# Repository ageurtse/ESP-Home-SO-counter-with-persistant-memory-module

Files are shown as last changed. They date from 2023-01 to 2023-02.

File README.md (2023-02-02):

# ESP Home, SO 4 channel counter with P1 interface

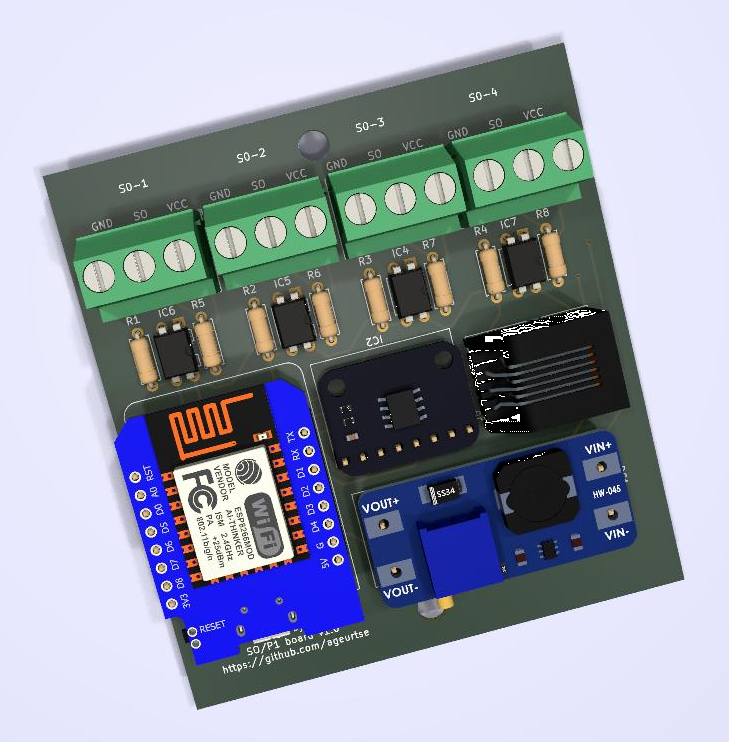
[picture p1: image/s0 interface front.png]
SO/P1 interface board


I wrote this software and developed the hardware because i was in the need of a device which could count my pulses from a water meter and from my solar pannels. 
The default counter from within ESPHome does the thrick, one could also preserve te counted value in the memory off a ESP device. 
But on my electrical meter which counts 2000 pulses per kW it will wearout in a couple of days. 

So i wen't searching and found this beaty which doesn't coast that much at all. 
https://www.adafruit.com/product/1895

After finding the device i need a way to use it in home assistant, that was for me as a hobby programmer the hardes part, first search for a library which could do the trick. 
and second how to interface the library with ESPHome so i could use it. 

For the library a big thanks to @RobTillart for his great library https://github.com/RobTillaart/FRAM_I2C which i'm implementing in it. 

I'm still working on a test setup, next step is to develop a need 4 wat SO circuit and PCB so one could rebuild.

I found a realy big bug in the hardware, the fourth SO input can't be working, becaus off pulling down the TX inpunt on the ESP8266. When pulling this one down at boot, the device won't boot.

## Description about the FRAM module.

FRAM stands for Ferroelectric RAM - https://en.wikipedia.org/wiki/Ferroelectric_RAM

FRAM memory is much faster than EEPROM and almost as fast as (Arduino UNO) RAM. Another important feature FRAM has in common with EEPROM is that FRAM keeps its content after a reboot as it is non-volatile, even for years. That makes it ideal to store configuration or logging data in a project.
## Operational

There are 2 parts that one should keep in mind.

**First:**
One should make use off i2cfram.h this is the interface file between ESPHome and the library from https://github.com/RobTillaart/FRAM_I2C
in this file there is a setup part, where at boot the device is looking for a memory module and initializes it. 
further there are 2 function which could be called from within Lambda

float readfromfram(uint32_t memaddr), which reads from the given adres slot and returns a float value
void writetofram(uint32_t memaddr, float value), writes a float to the given memory slot
because of the use of floats in ESPhome, every memory slot contains 4 bytes. so if one give memaddr 10, it will write or read 4 bytes from addres 40

**Second:**
This is the yaml file.
For every counter i make use of a global variabel, which will be loaded from memory at boot time. 
It is also posible to (re)set te counters from Homeassistant. 

I disabled the timout so one could use the device without home assistant, i did a test run of 2 days without problems. 

There is the need for the custom component to initializes the memory module. 

From within the binary sensor, the global value is added with 1 at a time, on every count the new value is written to the memory module.

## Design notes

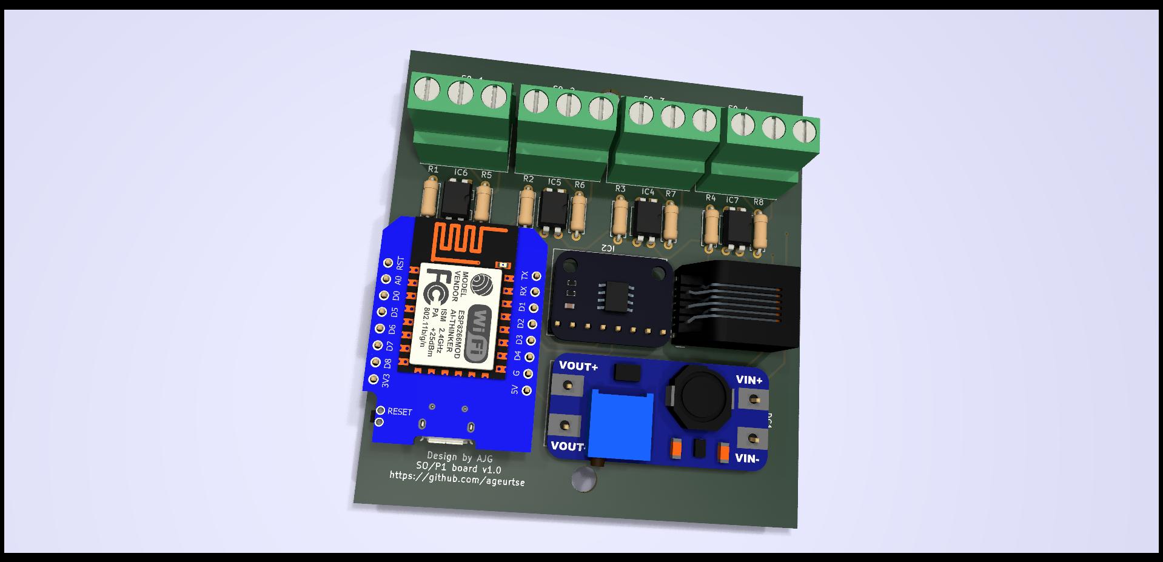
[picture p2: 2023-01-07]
Hardware/s0 interface/s0 interface.jpg

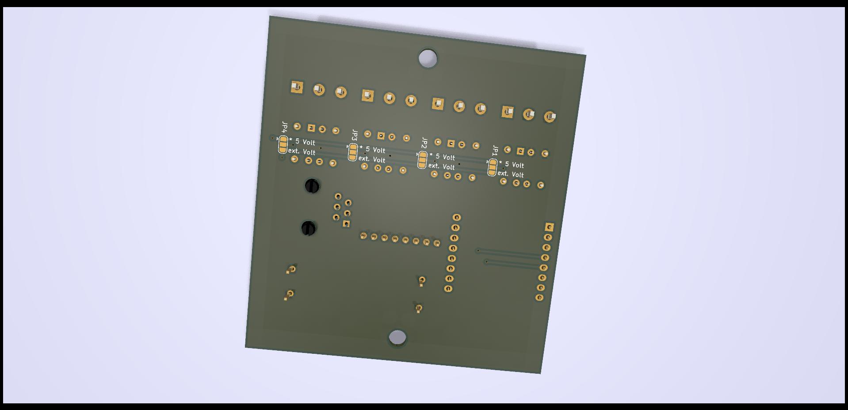
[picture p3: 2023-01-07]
Hardware/s0 interface/s0 interface back .jpg

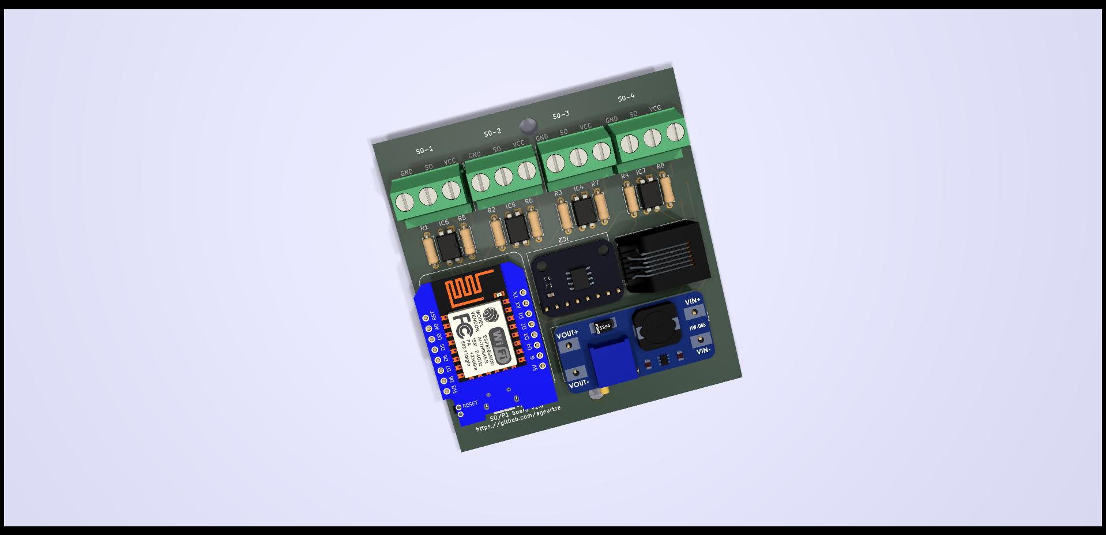
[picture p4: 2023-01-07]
Hardware/s0 interface/s0 interface front.jpg

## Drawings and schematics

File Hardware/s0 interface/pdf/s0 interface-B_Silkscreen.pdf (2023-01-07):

* 5 Volt ext. Volt * 5 Volt ext. Volt * 5 Volt ext. Volt * 5 Volt ext. Volt JP1 JP2 JP3 JP4

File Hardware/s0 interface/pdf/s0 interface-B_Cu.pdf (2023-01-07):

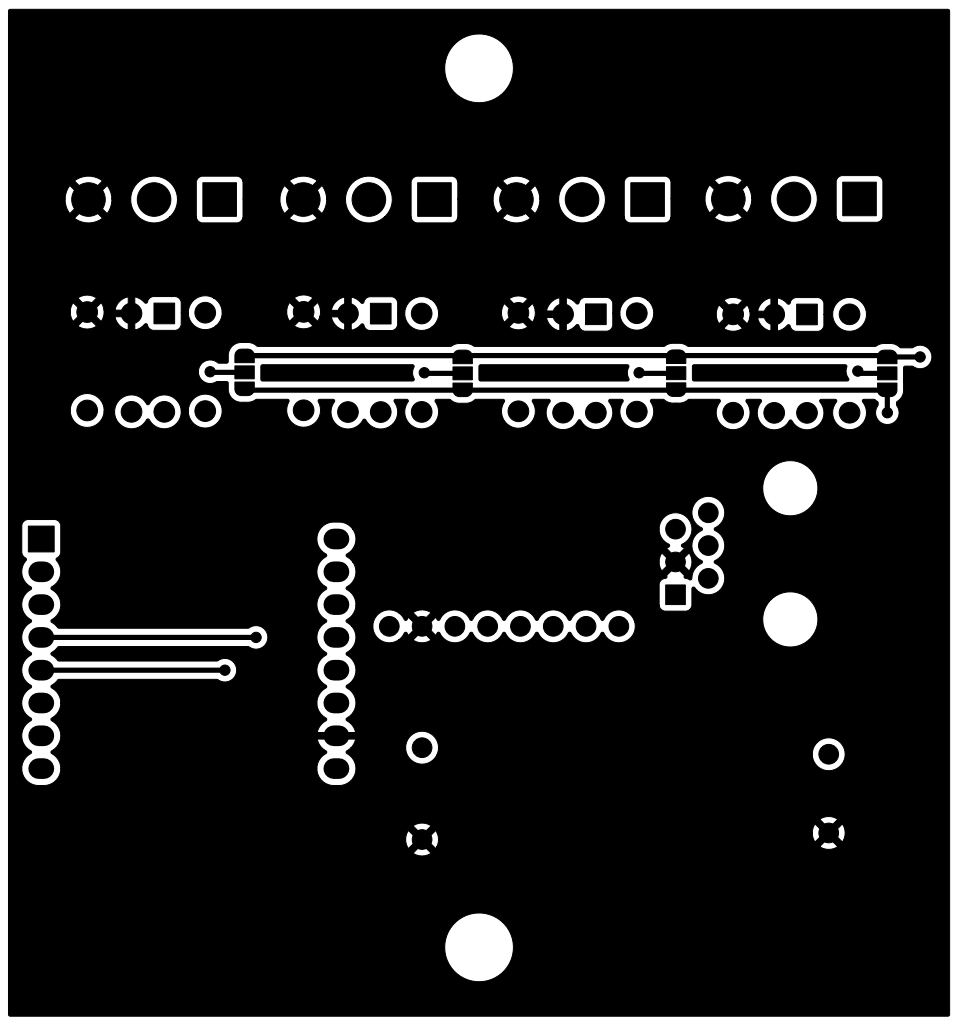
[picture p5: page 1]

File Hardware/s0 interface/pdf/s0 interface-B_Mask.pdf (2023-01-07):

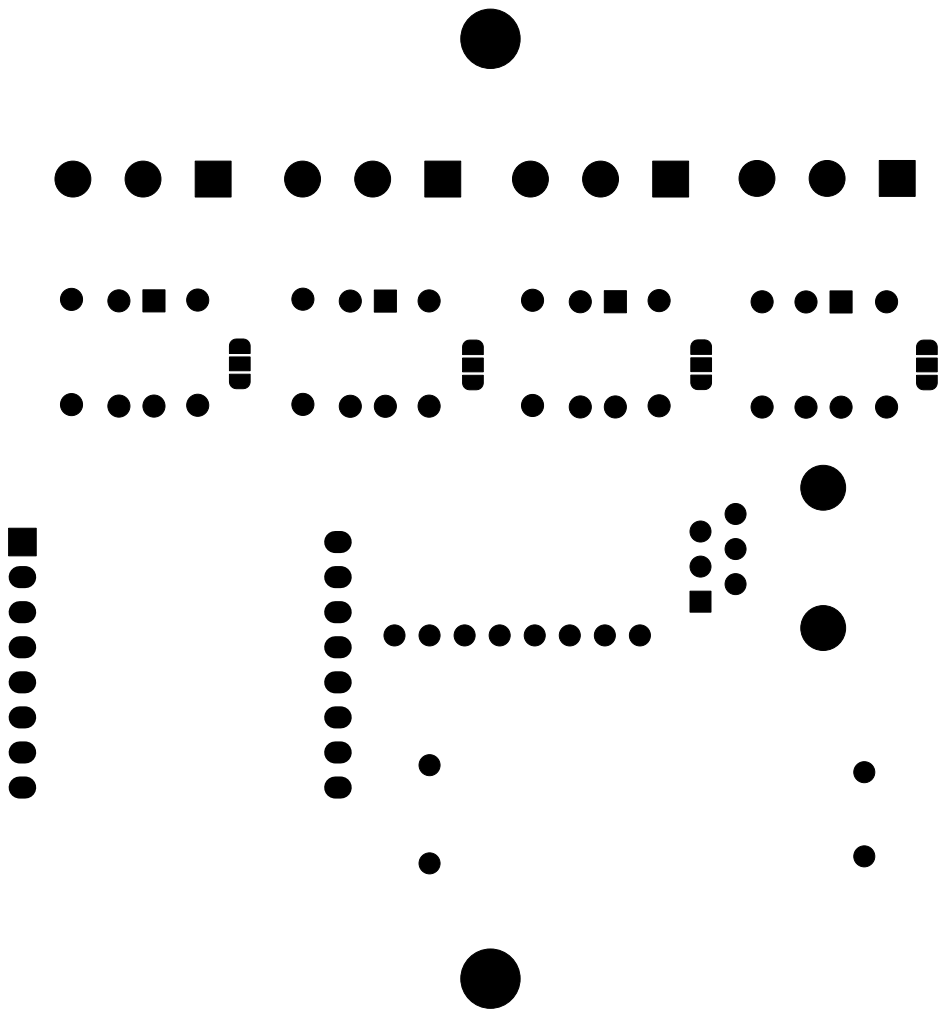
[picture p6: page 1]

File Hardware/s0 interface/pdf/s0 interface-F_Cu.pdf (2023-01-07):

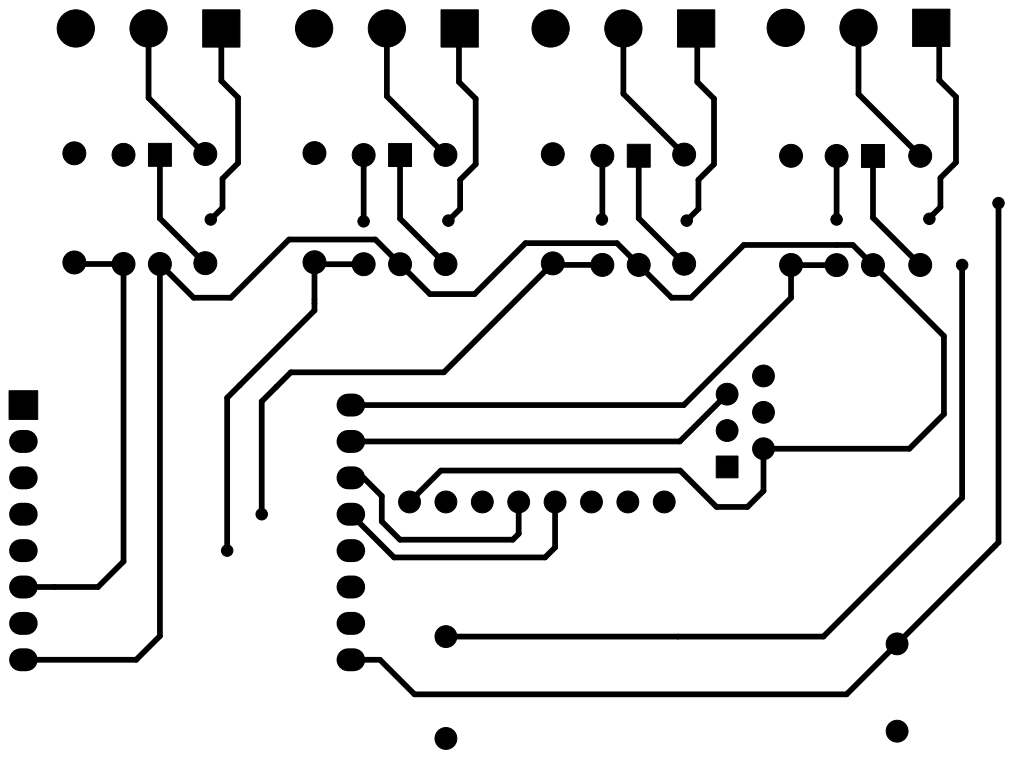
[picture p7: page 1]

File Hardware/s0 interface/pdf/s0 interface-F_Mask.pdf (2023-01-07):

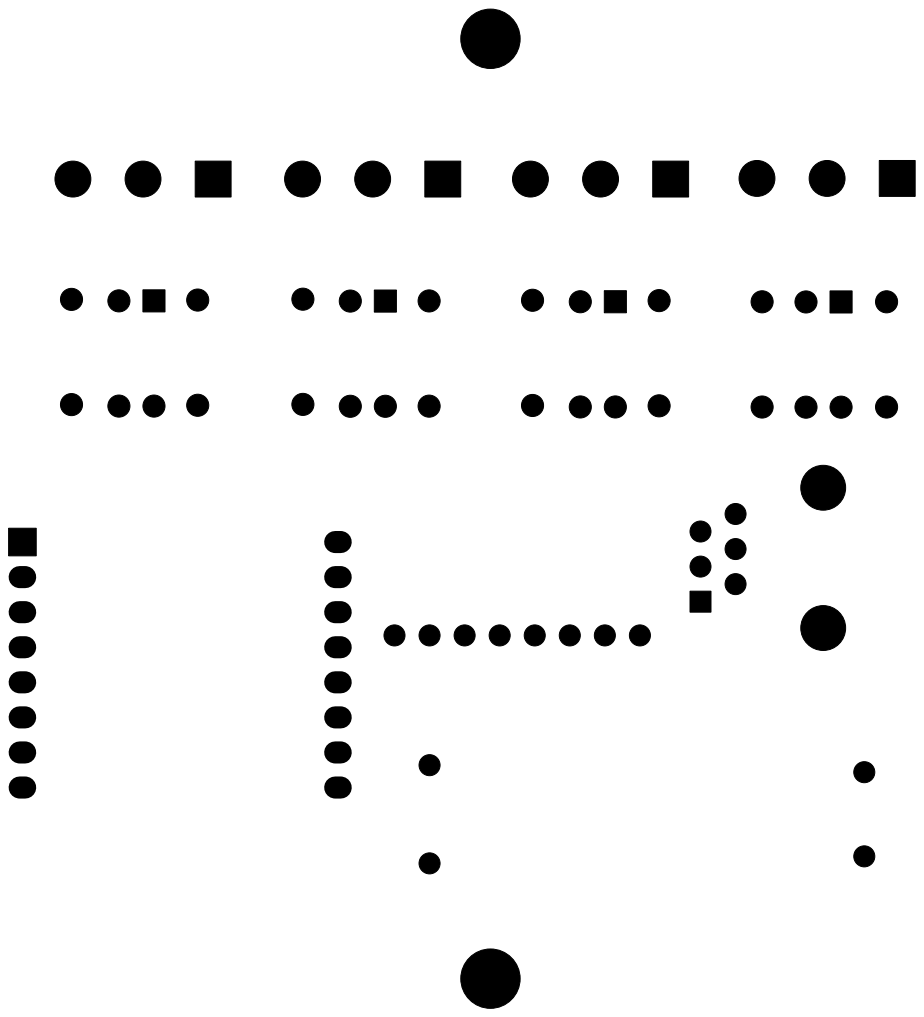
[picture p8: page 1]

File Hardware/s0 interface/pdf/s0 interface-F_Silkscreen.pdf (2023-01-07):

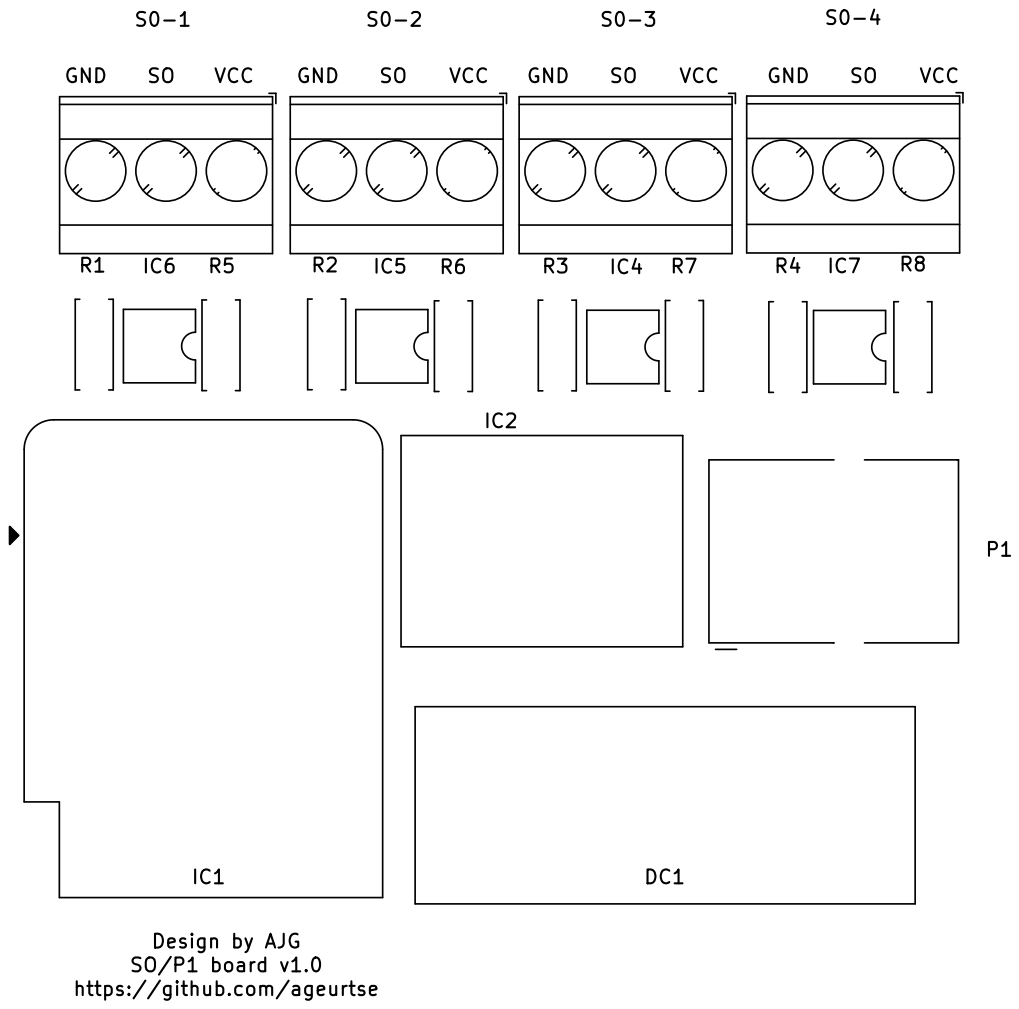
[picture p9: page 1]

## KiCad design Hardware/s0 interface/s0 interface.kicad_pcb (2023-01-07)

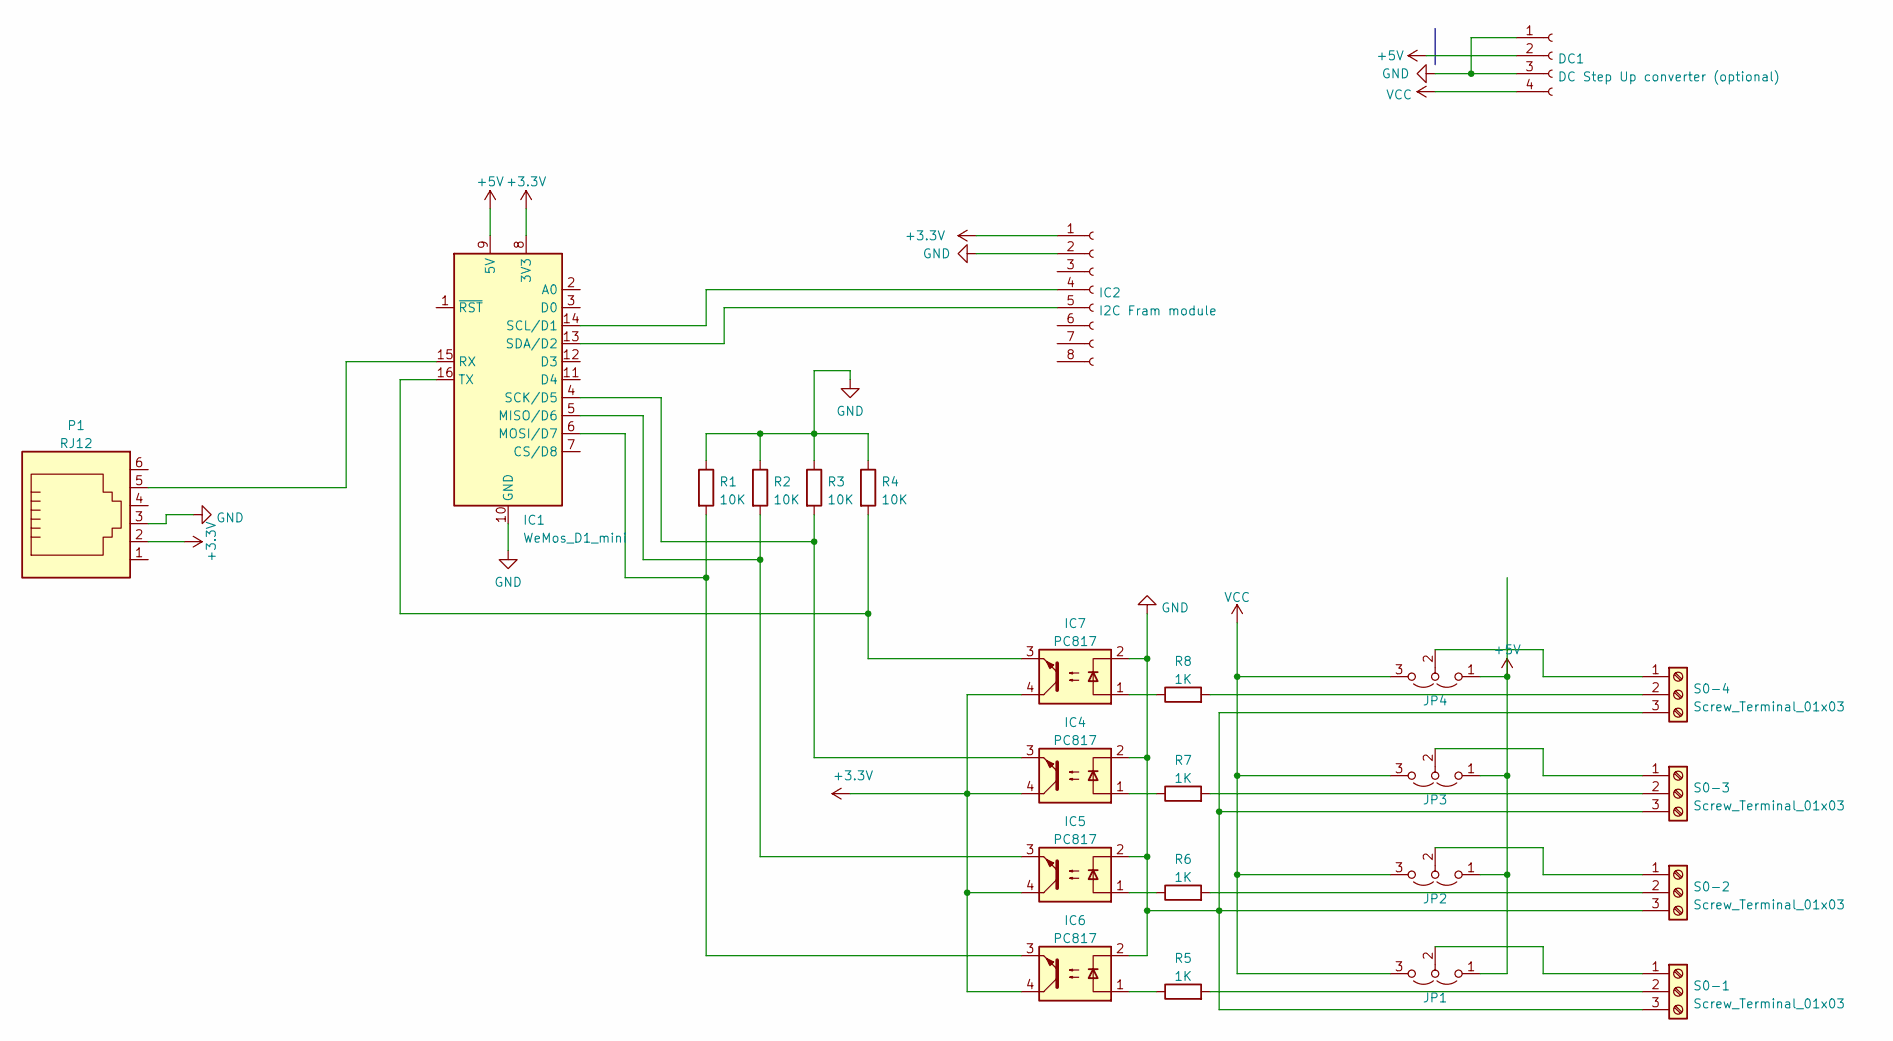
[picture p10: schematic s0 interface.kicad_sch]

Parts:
DC1: DC Step Up converter (optional); dcdc converter
IC1: WeMos_D1_mini; WEMOS_D1_mini_light
IC2: I2C Fram module; I2C FRAM Board
IC4, IC5, IC6, IC7: PC817; DIP-4_W7.62mm
JP1, JP2, JP3, JP4: Jumper_3_Open; SolderJumper-3_P1.3mm_Open_RoundedPad1.0x1.5mm
P1: RJ12; RJ12_Amphenol_54601
R1, R2, R3, R4: 10K; R_Axial_DIN0207_L6.3mm_D2.5mm_P7.62mm_Horizontal
R5, R6, R7, R8: 1K; R_Axial_DIN0207_L6.3mm_D2.5mm_P7.62mm_Horizontal
S0-1, S0-2, S0-3, S0-4: Screw_Terminal_01x03; TerminalBlock_Phoenix_MKDS-3-3-5.08_1x03_P5.08mm_Horizontal

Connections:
+3.3V: IC1.8 (3V3), IC2.1, IC4.4, IC5.4, IC6.4, IC7.4, P1.2
+5V: DC1.2, IC1.9 (5V), JP1.1 (A), JP2.1 (A), JP3.1 (A), JP4.1 (A)
GND: DC1.1, DC1.3, IC1.10 (GND), IC2.2, IC4.2, IC5.2, IC6.2, IC7.2, P1.3, R1.1, R2.1, R3.1, R4.1, S0-1.3, S0-2.3, S0-3.3, S0-4.3
unnamed: IC1.4 (SCK/D5), IC4.3, R3.2
unnamed: IC1.5 (MISO/D6), IC5.3, R2.2
unnamed: IC1.6 (MOSI/D7), IC6.3, R1.2
unnamed: IC1.13 (SDA/D2), IC2.5
unnamed: IC1.14 (SCL/D1), IC2.4
unnamed: IC1.15 (RX), P1.5
unnamed: IC1.16 (TX), IC7.3, R4.2
unnamed: IC4.1, R7.1
unnamed: IC5.1, R6.1
unnamed: IC6.1, R5.1
unnamed: IC7.1, R8.1
unnamed: JP1.2 (C), S0-1.1
unnamed: JP2.2 (C), S0-2.1
unnamed: JP3.2 (C), S0-3.1
unnamed: JP4.2 (C), S0-4.1
unnamed: R5.2, S0-1.2
unnamed: R6.2, S0-2.2
unnamed: R7.2, S0-3.2
unnamed: R8.2, S0-4.2
VCC: DC1.4, JP1.3 (B), JP2.3 (B), JP3.3 (B), JP4.3 (B)

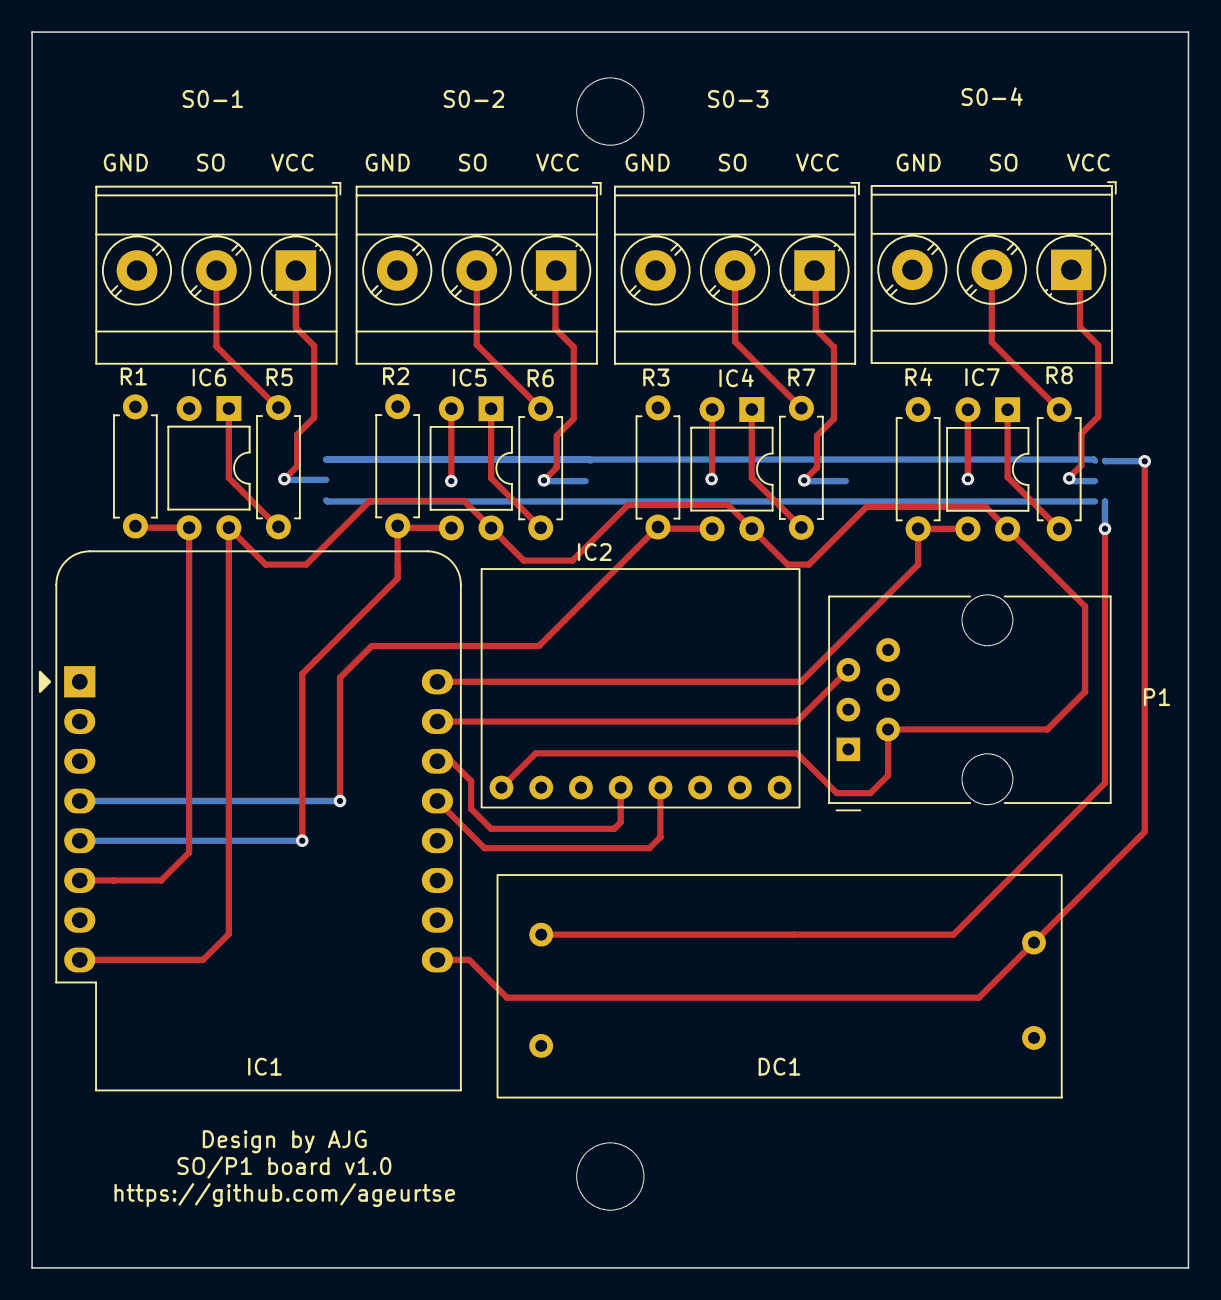
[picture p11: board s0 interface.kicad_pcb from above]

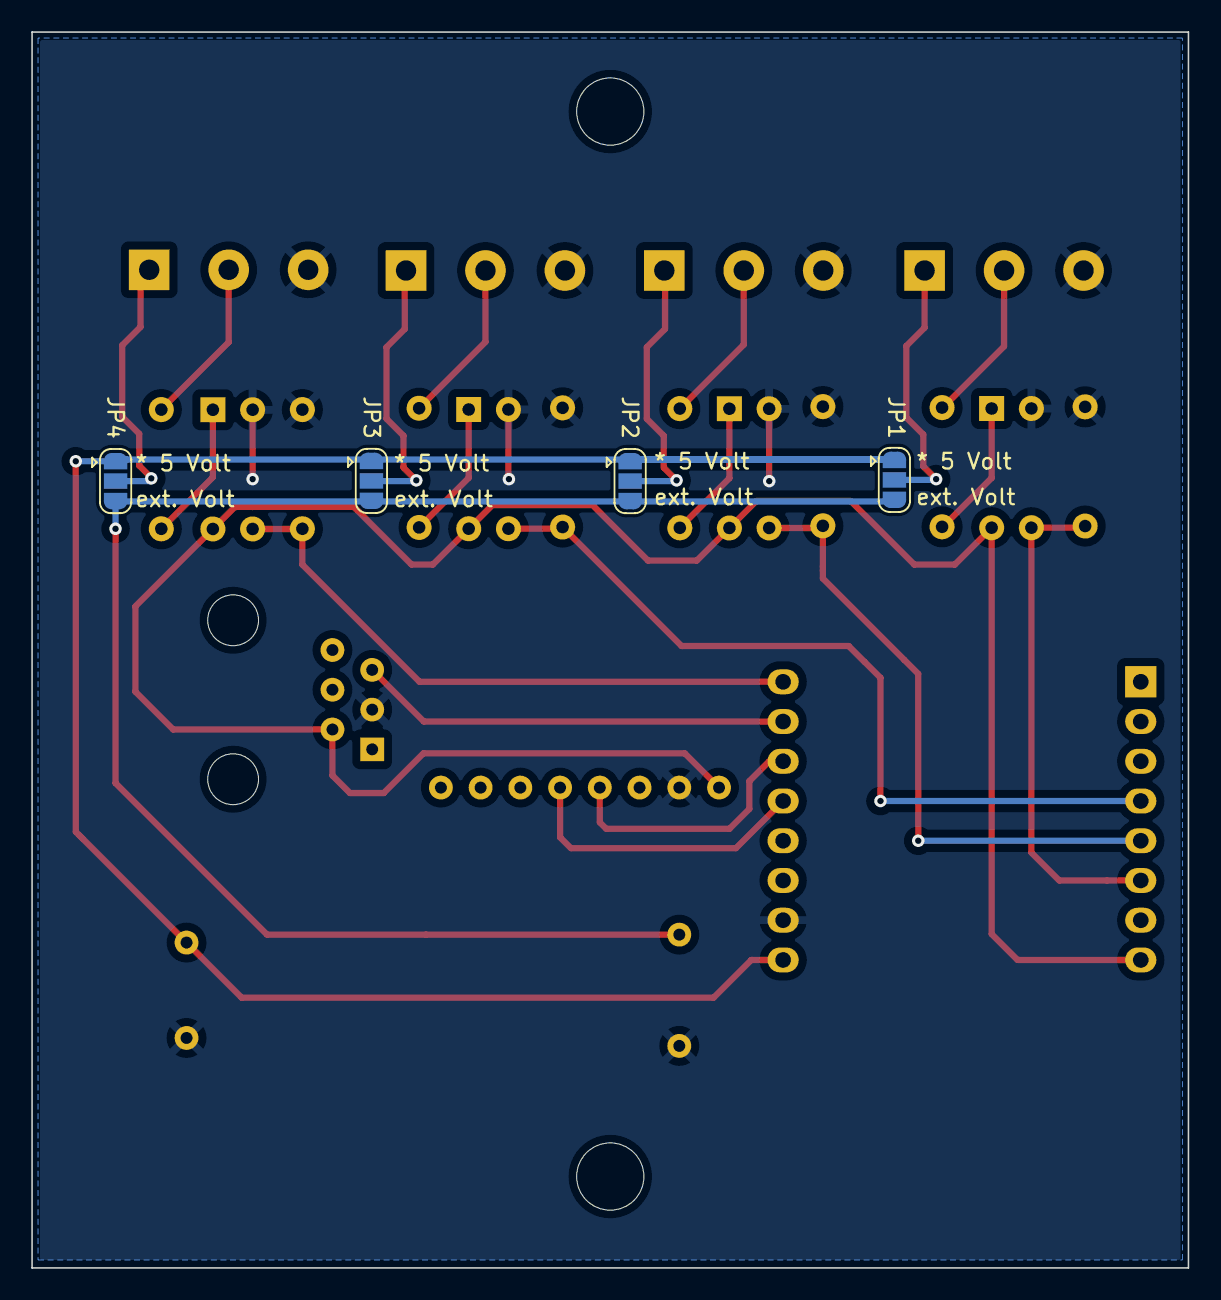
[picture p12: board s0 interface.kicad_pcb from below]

Board: 2 copper layers, 73.9 x 79.0 mm, 24 parts (4 on the bottom side), 23 nets.

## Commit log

2022-12-27 Add files via upload
    First upload of the files, it is all in a test stage, working is stil in progress, need to comment stuff inside the files.
    Later on try to make some hardware to runt it on, hardware should be good for 4 or 8 so inputs.
2023-01-07 hardware
    added hardware and update software
    [s0 interface-B_Cu.gbr, s0 interface-B_Mask.gbr, s0 interface-B_Paste.gbr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]
